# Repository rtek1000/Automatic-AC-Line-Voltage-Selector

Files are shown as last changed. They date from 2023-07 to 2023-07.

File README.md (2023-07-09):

# Automatic-AC-Line-Voltage-Selector
Automatic selector for 110VAC or 220VAC

- Usable for equipment that works with only 110V (to protect against wrong connection to 220V) or for 110V / 220V devices with manual switch selection.
- - It can operate with only 1 relay, but the 47V zener diode (D4, D5) must be kept in the scheme so as not to force the MOSFET (Q2).
-
- Operating mode is simple: the normally closed contact (NC) is for higher voltage connection (220V), when the AC line voltage is about 140Vac or less, the relay is activated.
- - The circuit has no hysteresis, so it may oscillate if the AC line voltage is at the threshold.
-
- Note: The wire colors in the example are merely illustrative:

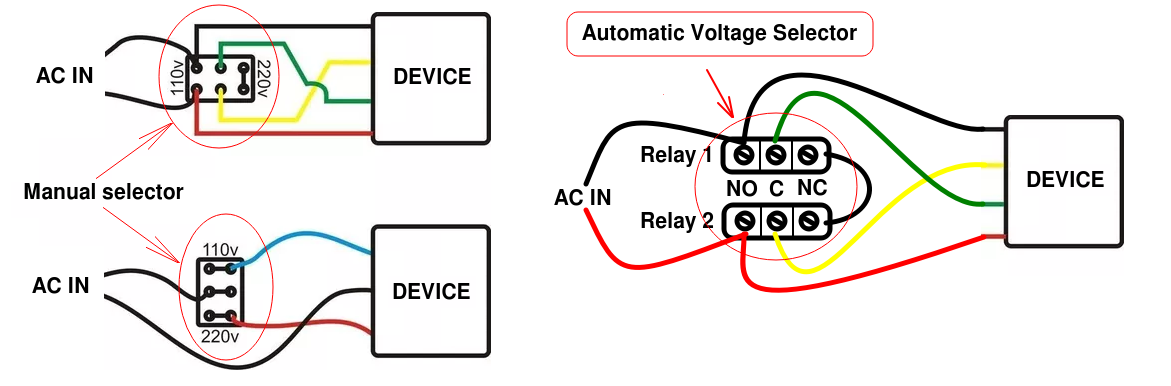
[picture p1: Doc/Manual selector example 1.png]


Schematic:
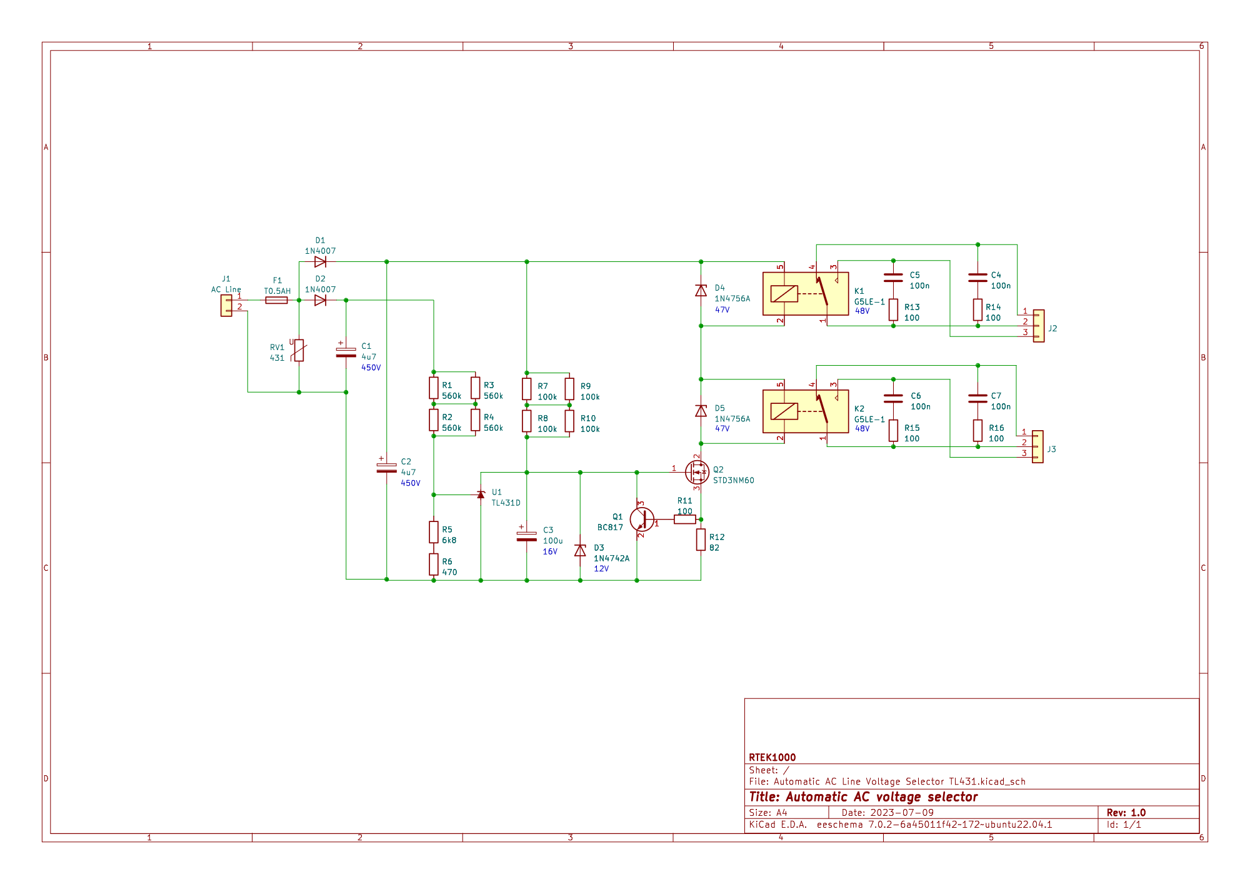
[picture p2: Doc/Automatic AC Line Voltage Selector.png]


Board:
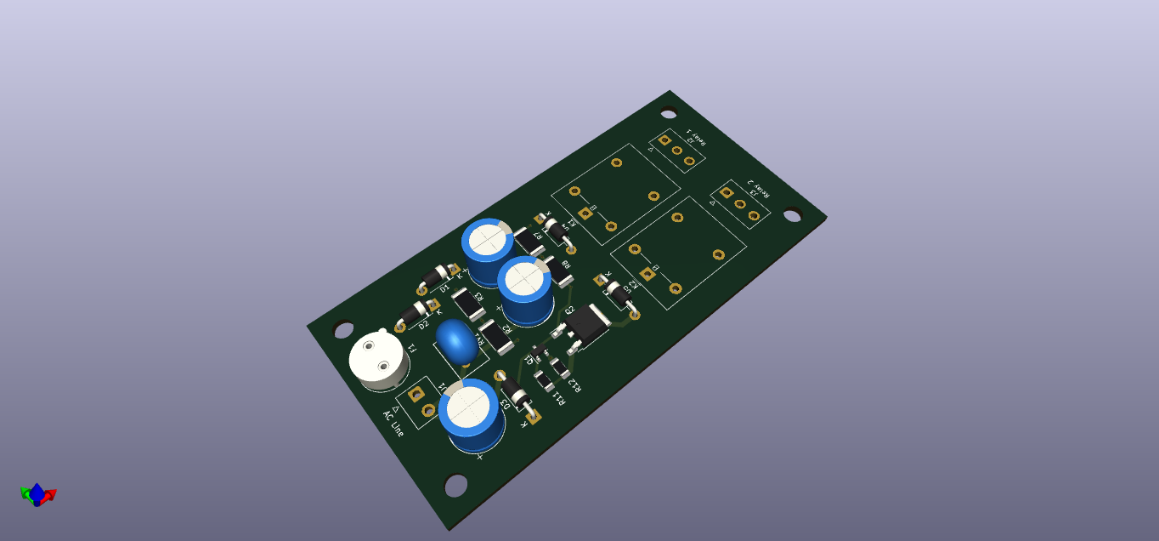
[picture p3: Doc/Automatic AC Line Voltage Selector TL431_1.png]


## Licence:
- Hardware:

Released under CERN OHL 1.2: https://ohwr.org/cernohl

- This library is distributed in the hope that it will be useful, but WITHOUT ANY WARRANTY; without even the implied warranty of MERCHANTABILITY or FITNESS FOR A PARTICULAR PURPOSE.

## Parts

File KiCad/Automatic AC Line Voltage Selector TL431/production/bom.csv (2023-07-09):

Designator | Footprint | Quantity | Value | LCSC Part #
C1, C2 | CP_Radial_D10.0mm_P5.00mm | 2 | 4u7
C3 | CP_Radial_D10.0mm_P2.50mm | 1 | 100u
C4, C5, C6, C7 | 1812 | 4 | 100n
D1, D2 | D_DO-41_SOD81_P7.62mm_Horizontal | 2 | 1N4007
D3 | D_DO-41_SOD81_P10.16mm_Horizontal | 1 | 1N4742A
D4, D5 | D_DO-41_SOD81_P10.16mm_Horizontal | 2 | 1N4756A
F1 | Fuseholder_TR5_Littelfuse_No560_No460 | 1 | Fuse
J1 | TE_826576-2_1x02_P3.96mm_Vertical | 1 | AC Line
J2, J3 | TE_826576-3_1x03_P3.96mm_Vertical | 2 | Conn_01x03
K1, K2 | Relay_SPDT_Omron-G5LE-1 | 2 | G5LE-1
Q1 | SOT-23 | 1 | BC817
Q2 | TO-252-2 | 1 | STD3NM60
R1, R2, R3, R4 | 2512 | 4 | 560k
R10, R7, R8, R9 | 2512 | 4 | 100k
R11, R13, R14, R15, R16 | 1206 | 5 | 100
R12 | 1206 | 1 | 82
R5 | 1206 | 1 | 6k8
R6 | 1206 | 1 | 470
RV1 | RV_Disc_D9mm_W6.1mm_P5mm | 1 | 271
U1 | SOIC-8_3.9x4.9mm_P1.27mm | 1 | TL431D

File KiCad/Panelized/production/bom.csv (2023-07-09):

Designator | Footprint | Quantity | Value | LCSC Part #
C1_2, C1, C2_2, C2 | CP_Radial_D10.0mm_P5.00mm | 4 | 4u7
C3_2, C3 | CP_Radial_D10.0mm_P2.50mm | 2 | 100u
C4_2, C4, C5_2, C5, C6_2, C6, C7_2, C7 | 1812 | 8 | 100n
D1_2, D1, D2_2, D2 | D_DO-41_SOD81_P7.62mm_Horizontal | 4 | 1N4007
D3_2, D3 | D_DO-41_SOD81_P10.16mm_Horizontal | 2 | 1N4742A
D4_2, D4, D5_2, D5 | D_DO-41_SOD81_P10.16mm_Horizontal | 4 | 1N4756A
F1_2, F1 | Fuseholder_TR5_Littelfuse_No560_No460 | 2 | Fuse
J1_2, J1 | TE_826576-2_1x02_P3.96mm_Vertical | 2 | AC Line
J2_2, J2, J3_2, J3 | TE_826576-3_1x03_P3.96mm_Vertical | 4 | Conn_01x03
K1_2, K1, K2_2, K2 | Relay_SPDT_Omron-G5LE-1 | 4 | G5LE-1
Q1_2, Q1 | SOT-23 | 2 | BC817
Q2_2, Q2 | TO-252-2 | 2 | STD3NM60
R1_2, R1, R2_2, R2, R3_2, R3, R4_2, R4 | 2512 | 8 | 560k
R10_2, R10, R7_2, R7, R8_2, R8, R9_2, R9 | 2512 | 8 | 100k
R11_2, R11, R13_2, R13, R14_2, R14, R15_2, R15, R16_2, R16 | 1206 | 10 | 100
R12_2, R12 | 1206 | 2 | 82
R5_2, R5 | 1206 | 2 | 6k8
R6_2, R6 | 1206 | 2 | 470
RV1_2, RV1 | RV_Disc_D9mm_W6.1mm_P5mm | 2 | 271
U1_2, U1 | SOIC-8_3.9x4.9mm_P1.27mm | 2 | TL431D

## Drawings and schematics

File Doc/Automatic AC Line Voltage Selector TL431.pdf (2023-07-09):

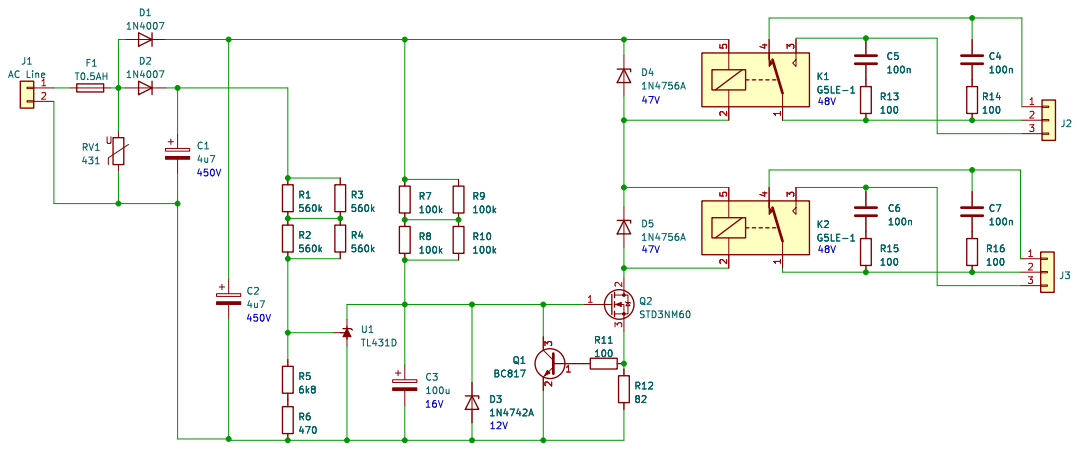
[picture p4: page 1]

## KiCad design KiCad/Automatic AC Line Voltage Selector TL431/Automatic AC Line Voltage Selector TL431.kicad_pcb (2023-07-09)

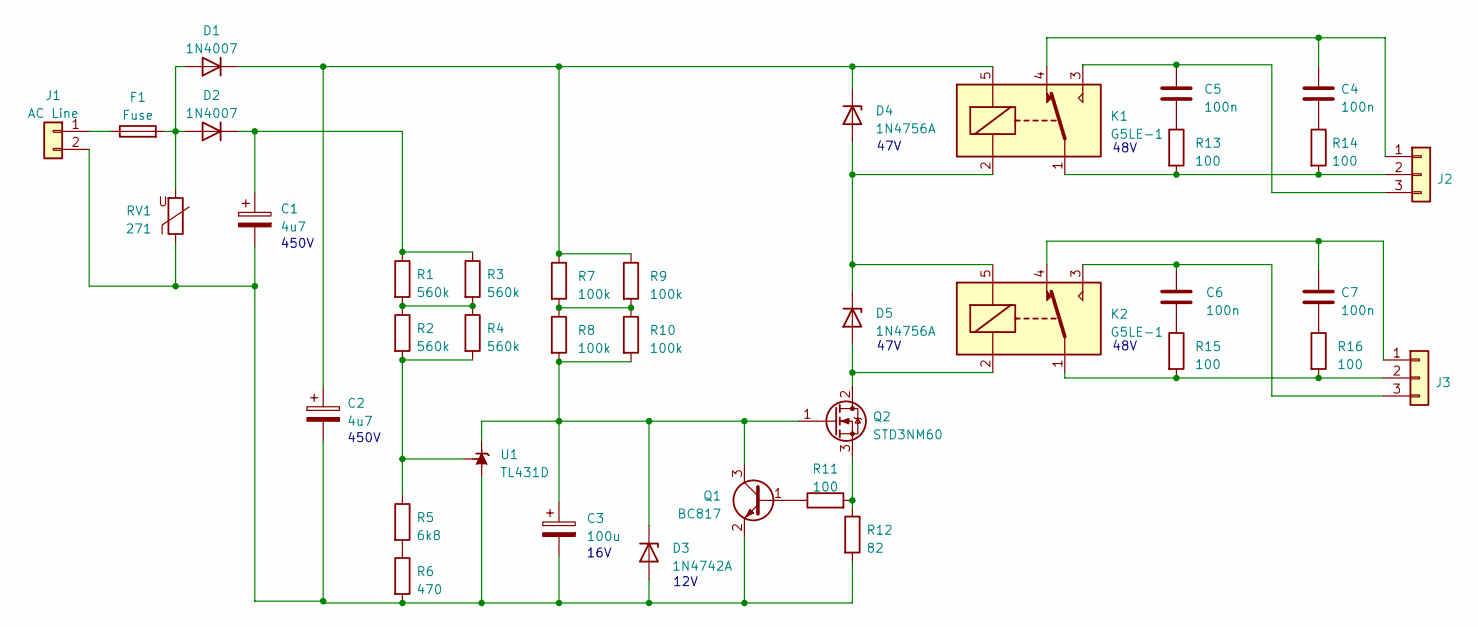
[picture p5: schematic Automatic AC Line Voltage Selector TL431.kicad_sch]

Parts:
C1, C2: 4u7; CP_Radial_D10.0mm_P5.00mm
C3: 100u; CP_Radial_D10.0mm_P2.50mm
C4, C5, C6, C7: 100n; C_1812_4532Metric
D1, D2: 1N4007; D_DO-41_SOD81_P7.62mm_Horizontal
D3: 1N4742A; D_DO-41_SOD81_P10.16mm_Horizontal
D4, D5: 1N4756A; D_DO-41_SOD81_P10.16mm_Horizontal
F1: Fuse; Fuseholder_TR5_Littelfuse_No560_No460
J1: AC Line; TE_826576-2_1x02_P3.96mm_Vertical
J2, J3: Conn_01x03; TE_826576-3_1x03_P3.96mm_Vertical
K1, K2: G5LE-1; Relay_SPDT_Omron-G5LE-1
Q1: BC817; SOT-23
Q2: STD3NM60; TO-252-2
R1, R2, R3, R4: 560k; R_2512_6332Metric_Pad1.40x3.35mm_HandSolder
R5: 6k8; R_1206_3216Metric_Pad1.30x1.75mm_HandSolder
R6: 470; R_1206_3216Metric_Pad1.30x1.75mm_HandSolder
R7, R8, R9, R10: 100k; R_2512_6332Metric_Pad1.40x3.35mm_HandSolder
R11, R13, R14, R15, R16: 100; R_1206_3216Metric_Pad1.30x1.75mm_HandSolder
R12: 82; R_1206_3216Metric_Pad1.30x1.75mm_HandSolder
RV1: 271; RV_Disc_D9mm_W6.1mm_P5mm
U1: TL431D; SOIC-8_3.9x4.9mm_P1.27mm

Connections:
unnamed: C4.2, R14.1
unnamed: C5.2, R13.1
unnamed: C6.2, R15.1
unnamed: C7.2, R16.1
unnamed: D1.2 (A), D2.2 (A), F1.2, RV1.2
unnamed: C2.1, D1.1 (K), D4.1 (K), K1.5, R7.1, R9.1
unnamed: C1.1, D2.1 (K), R1.1, R3.1
unnamed: C1.2, C2.2, C3.2, D3.2 (A), J1.2, Q1.2 (E), R6.2, R12.2, RV1.1, U1.2 (A), U1.3 (A), U1.6 (A), U1.7 (A)
unnamed: C3.1, D3.1 (K), Q1.3 (C), Q2.1 (G), R8.2, R10.2, U1.1 (K)
unnamed: D4.2 (A), D5.1 (K), K1.2, K2.5
unnamed: D5.2 (A), K2.2, Q2.2 (D)
unnamed: F1.1, J1.1
unnamed: C4.1, J2.1, K1.4
unnamed: J2.2, K1.1, R13.2, R14.2
unnamed: C5.1, J2.3, K1.3
unnamed: C7.1, J3.1, K2.4
unnamed: J3.2, K2.1, R15.2, R16.2
unnamed: C6.1, J3.3, K2.3
unnamed: Q1.1 (B), R11.1
unnamed: Q2.3 (S), R11.2, R12.1
unnamed: R1.2, R2.1, R3.2, R4.1
unnamed: R5.2, R6.1
unnamed: R7.2, R8.1, R9.2, R10.1
unnamed: R2.2, R4.2, R5.1, U1.8 (REF)

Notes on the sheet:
48V
47V
450V
16V
12V

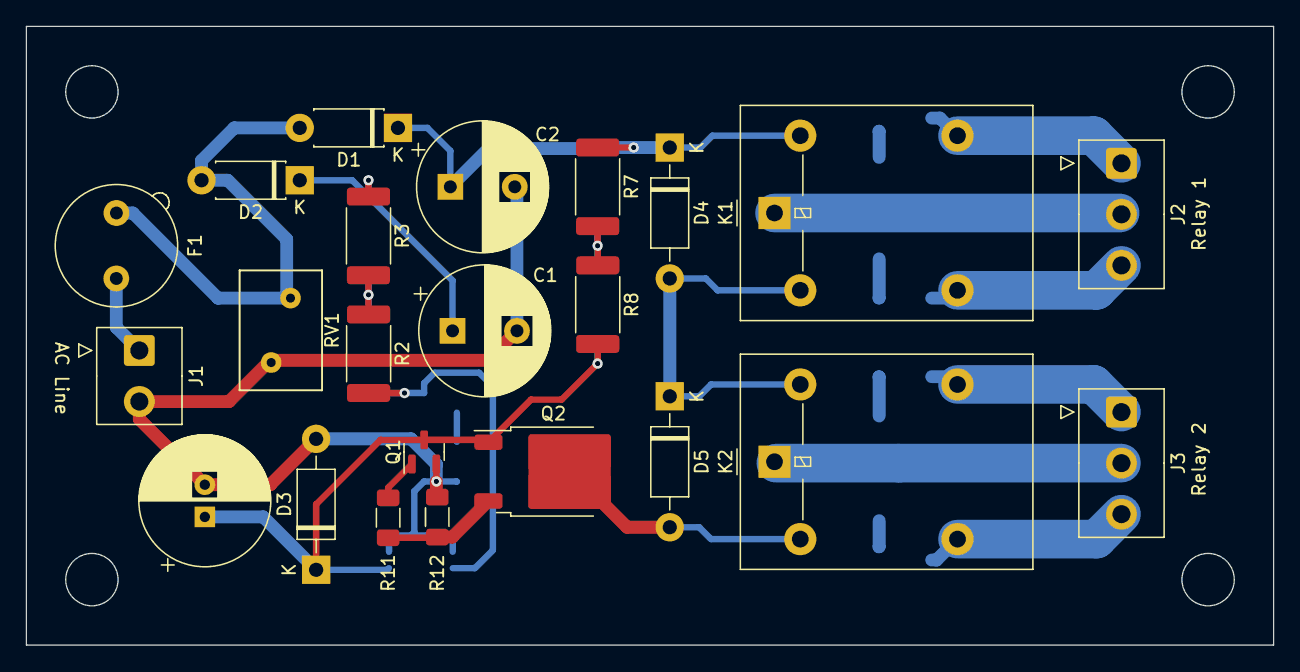
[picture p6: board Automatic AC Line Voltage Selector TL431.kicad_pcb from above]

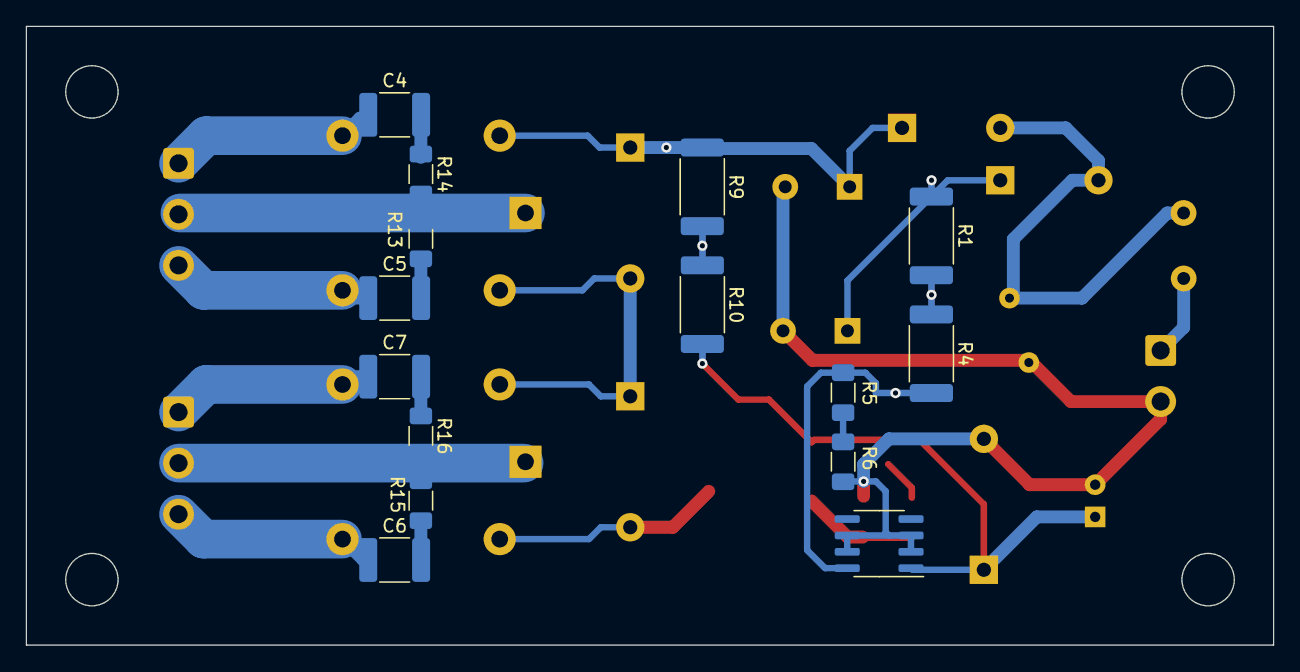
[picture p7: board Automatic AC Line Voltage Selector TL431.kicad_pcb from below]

Board: 2 copper layers, 96.8 x 48.0 mm, 38 parts (15 on the bottom side), 24 nets.

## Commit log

2023-07-09 Create Automatic AC Line Voltage Selector.png
2023-07-09 Create Automatic AC Line Voltage Selector 1.png
